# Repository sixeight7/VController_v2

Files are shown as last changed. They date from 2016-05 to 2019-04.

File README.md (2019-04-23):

# VController version 2
Second version of the dedicated MIDI controller for Boss GP-10  / Roland GR-55 / Roland VG-99 and Zoom G3
The latest version is the VController version 3: https://github.com/sixeight7/VController_v3. The firmware of version 3 can be compiled for this hardware! That way you get all the features of version 3 for this device as well!

# Features
* Patch selection - view of patch names for all devices.
* Read and show correct effect state for all devices. Different colours for different types of effects (eg. modulation is blue, amps are red, delays are green, etc)
* GP10 and GR55: change fixed parameters and cc assigns on each patch. Display tells you which parameter is changed and buttons have a colour that shows you the type of FX you select.
* VG99: pedal simulates an FC300 for CTL-1 to CTL-8. Parameter names and colours displayed for the most common parameters. CC assigns and fixed parameters also possible.
* For fixed parameters three/four and five state switches can be programmed
* Zoom G3: support of patch names / control of the 6 effects (on/off) - FX name is displayed, tap tempo.
* Global Tap Tempo: all devices pick up the tempo from the V-Controller. There is the option to keep this tempo on all patches on all devices.
* US-20 simulation: smart muting of GP10, GR55 or VG99 by switching off the COSM guitar/synth/normal PU on the devices that are not active.
* Autobass mode: sends a CC message with the number of the lowest string that is being played (CC #15)

# Hardware
Teensy 3.2, 16 switches and 16 neopixel LEDs, 13 1602 LCD display, some additional parts and an enclosure.
See my project blog for details and schematic.

# Software
Developed on Teensy 3.2 
Make sure you have the https://bitbucket.org/fmalpartida/new-liquidcrystal/downloads/LiquidCrystal_V1.2.1.zip library installed. It is the only non-standard library used in this sketch.

Start with VController_v2.ino in the VController_v2 folder to browse this code. It has the main setup and loop from where all the other files are called.

I tried to seperate the different tasks of the VController in the different files. Complete seperation is not possible, but it helps a great deal in finding stuff back.

Short desciption of each file in the VController_v2 folder:

* VController_v2.ino: The main file, that will call all the other ones in the right order.
* Commands.ino: shows the commands that can be used in the configuration of the VController
* Config.ino: configuration of what each switch does (on a page)
* Devices.ino: contains the basic settings and variables for the devices.
* EEPROM.ino: deals with putting some settings in memory.
* LCD.ino: sets up hardware for the LCD and decides what to put on the screen.
* LEDs.ino: sets up the neopixel LEDs and decides when to light up which one.
* MIDI.ino: sets up the MIdI hardware and provides the basic functions
* MIDI_FC300.ino: deals with specific midi functions for the FC 300.
* MIDI_GP10.ino: deals with specific midi functions for the Boss GP-10.
* MIDI_GR55.ino: deals with specific midi functions for the Roland GR-55.
* MIDI_VG99.ino: deals with specific midi functions for the Roland VG-99.
* MIDI_ZG3.ino: deals with specific midi functions for the Zoom G3
* Page.ino: here a page of switches is read from the configuration and the correct MIDI function is called from here.
* Switch_check.ino: checks whether a switch is pressed, released or pressed for a longer time.
* Switch_control.ino: basically deals with patch changes and provides the framework for the stompbox modes.
* z_log.ino: Log of latest changes.

More details are up in my project blog.

# To do
* Adding Direct select
* Adding parameter range option - to allow programming devices from the VController
* Add song and set mode.

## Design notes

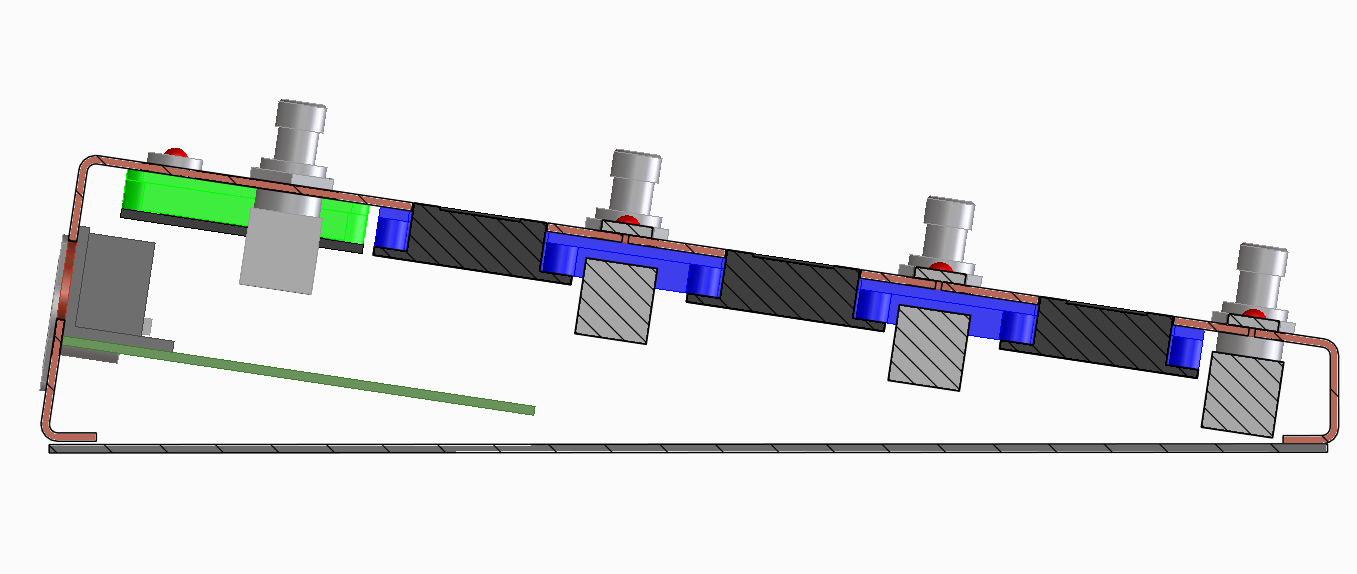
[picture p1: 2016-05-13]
Enclosure/Metal/side_view.png

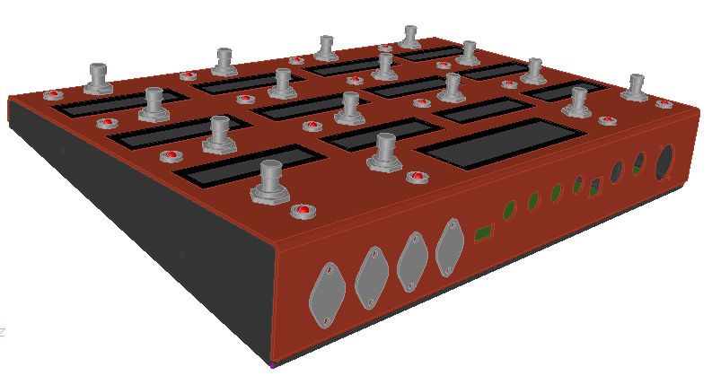
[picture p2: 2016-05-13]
Enclosure/VC2 final back.png

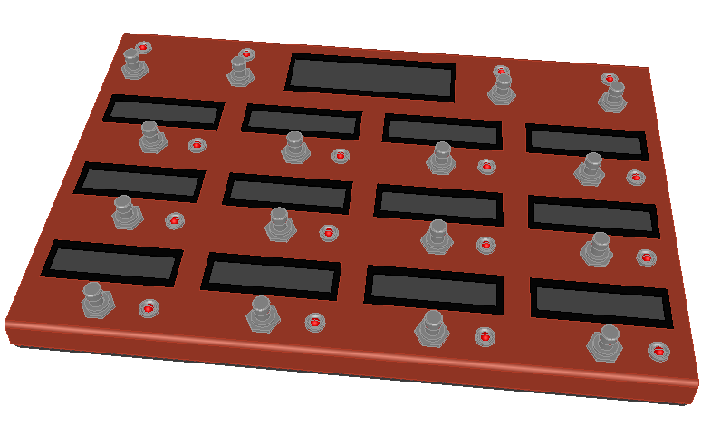
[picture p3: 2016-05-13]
Enclosure/VC2 final front.png

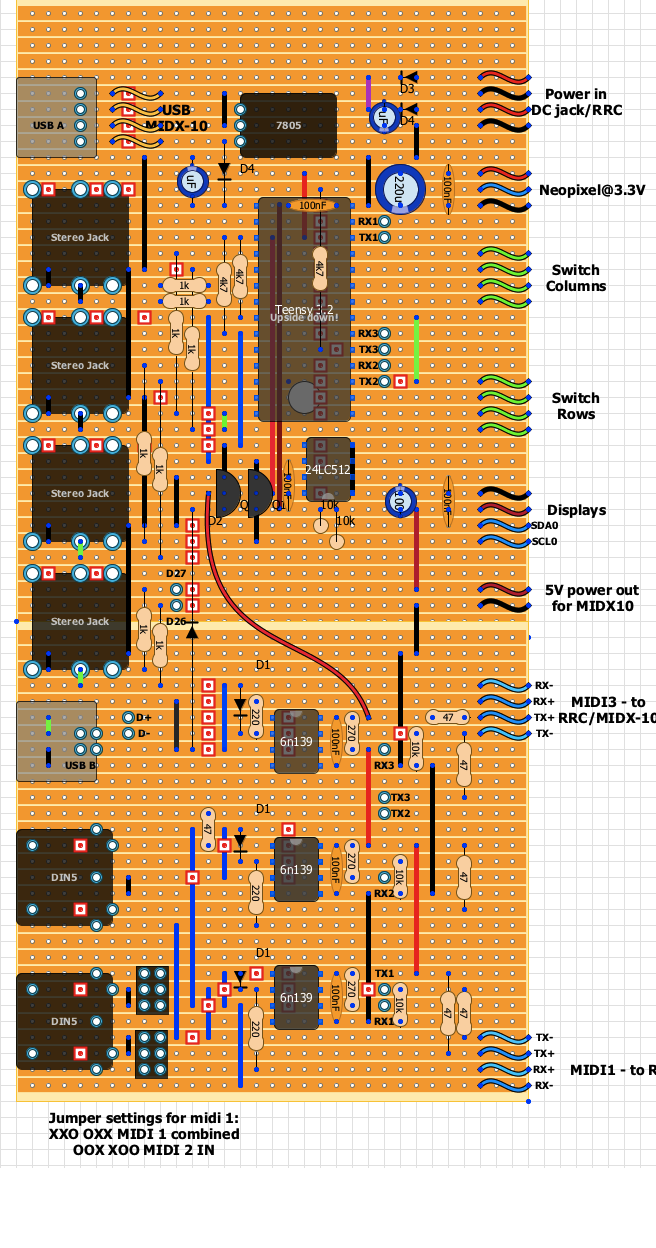
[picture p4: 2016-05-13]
PCB/VController PCB v2.4.png

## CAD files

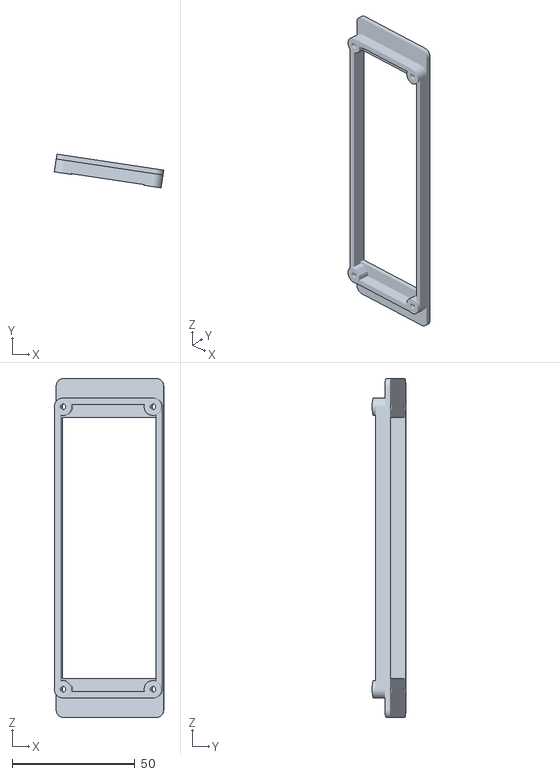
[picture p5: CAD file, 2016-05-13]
Enclosure/3D printing/Large LCD support diameter_2_5.stl
44.6 x 13.7 x 138.0

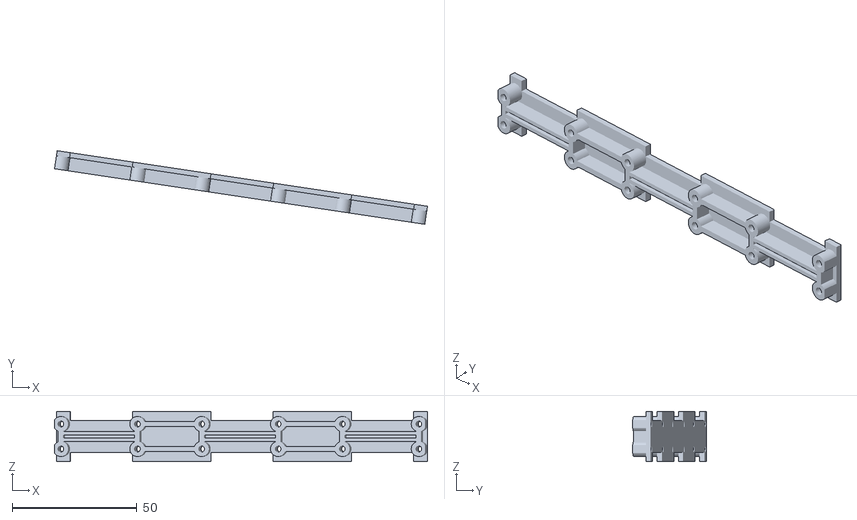
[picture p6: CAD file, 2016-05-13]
Enclosure/3D printing/Small 3xLCD support diameter_2_5.stl
149.4 x 29.5 x 20.2

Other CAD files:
Enclosure/Metal/bottom_sheet.dxf
Enclosure/Metal/top_sheet.dxf
Enclosure/Metal/bottom_sheet.dwg
Enclosure/Metal/top_sheet.dwg

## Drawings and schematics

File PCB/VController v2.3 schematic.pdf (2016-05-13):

220 47 | 47 | 1k8 270 220 4747 | 1k8 270 220 4747 | 1k8 270

A

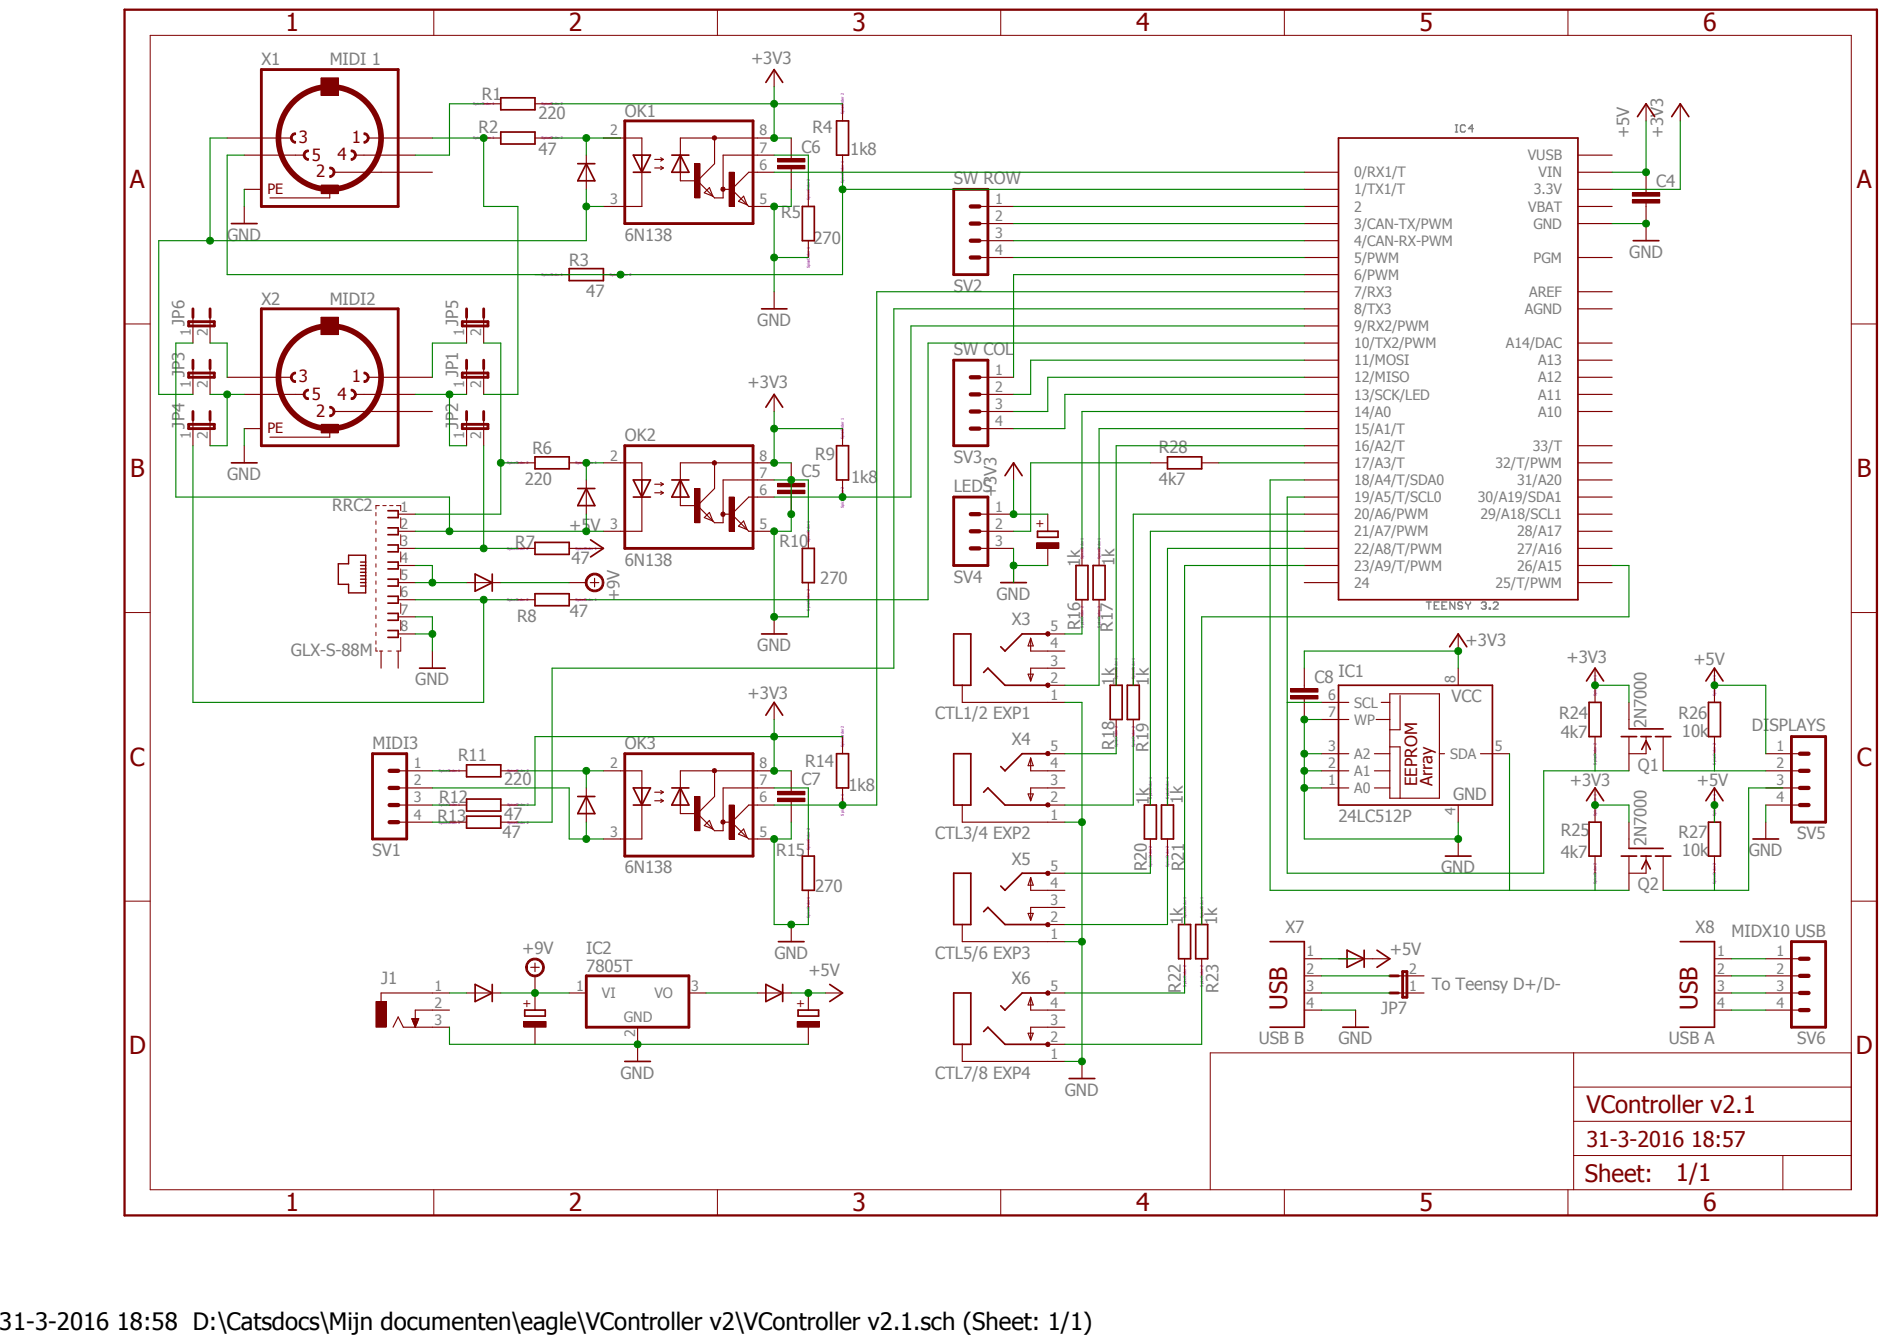
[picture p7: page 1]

5 | | SW ROW

SpiceOrder 1 SpiceOrder 2

31-3-2016 18:58 D:\Catsdocs\Mijn documenten\eagle\VController v2\VController v2.1.sch (Sheet: 1/1)

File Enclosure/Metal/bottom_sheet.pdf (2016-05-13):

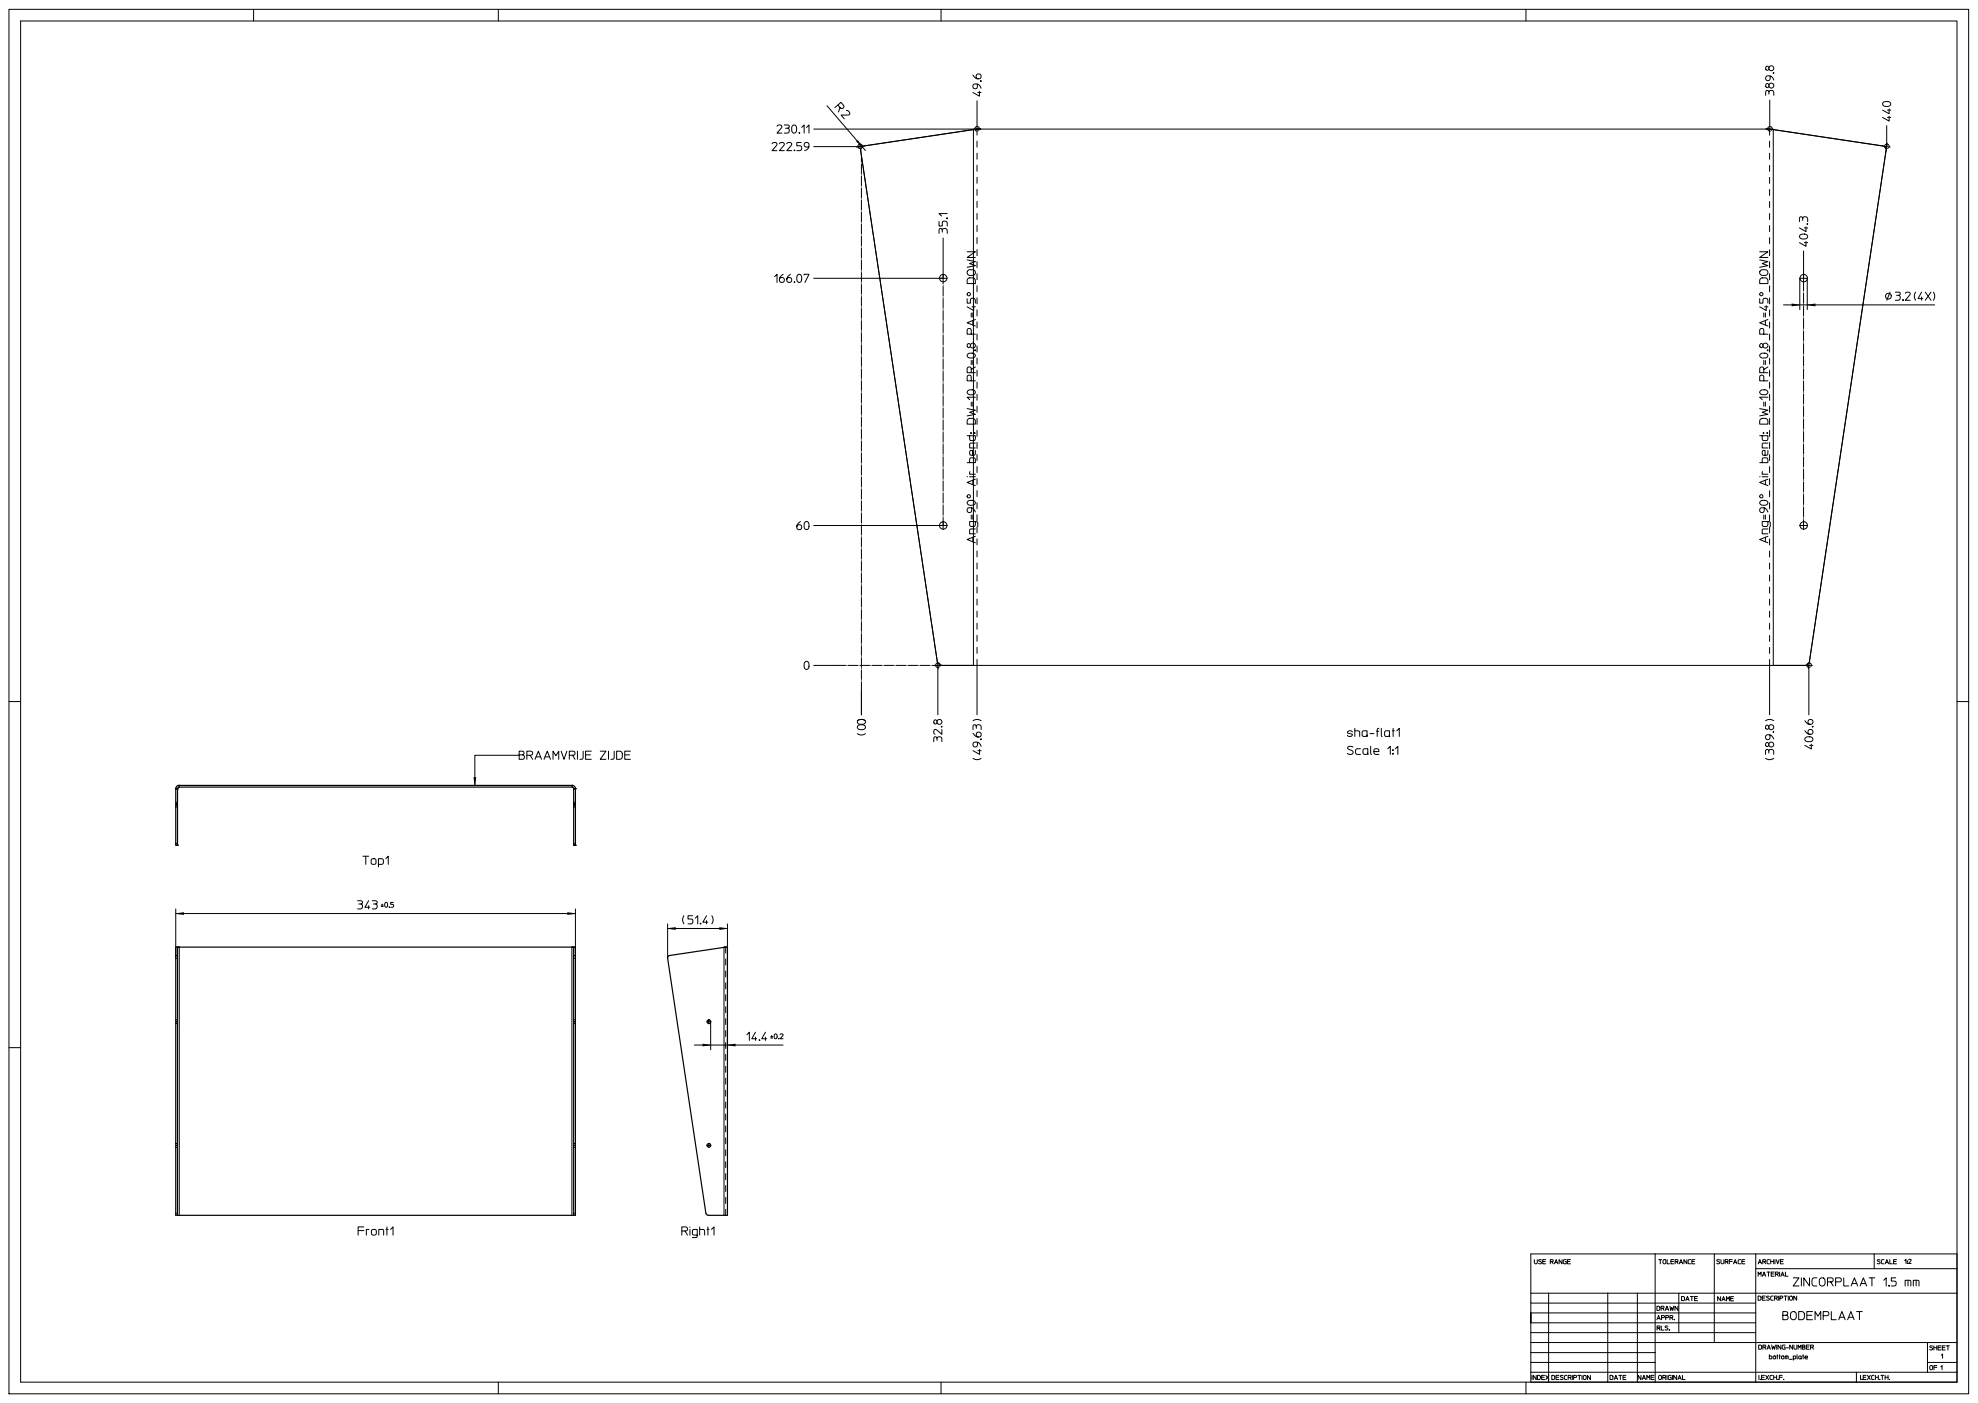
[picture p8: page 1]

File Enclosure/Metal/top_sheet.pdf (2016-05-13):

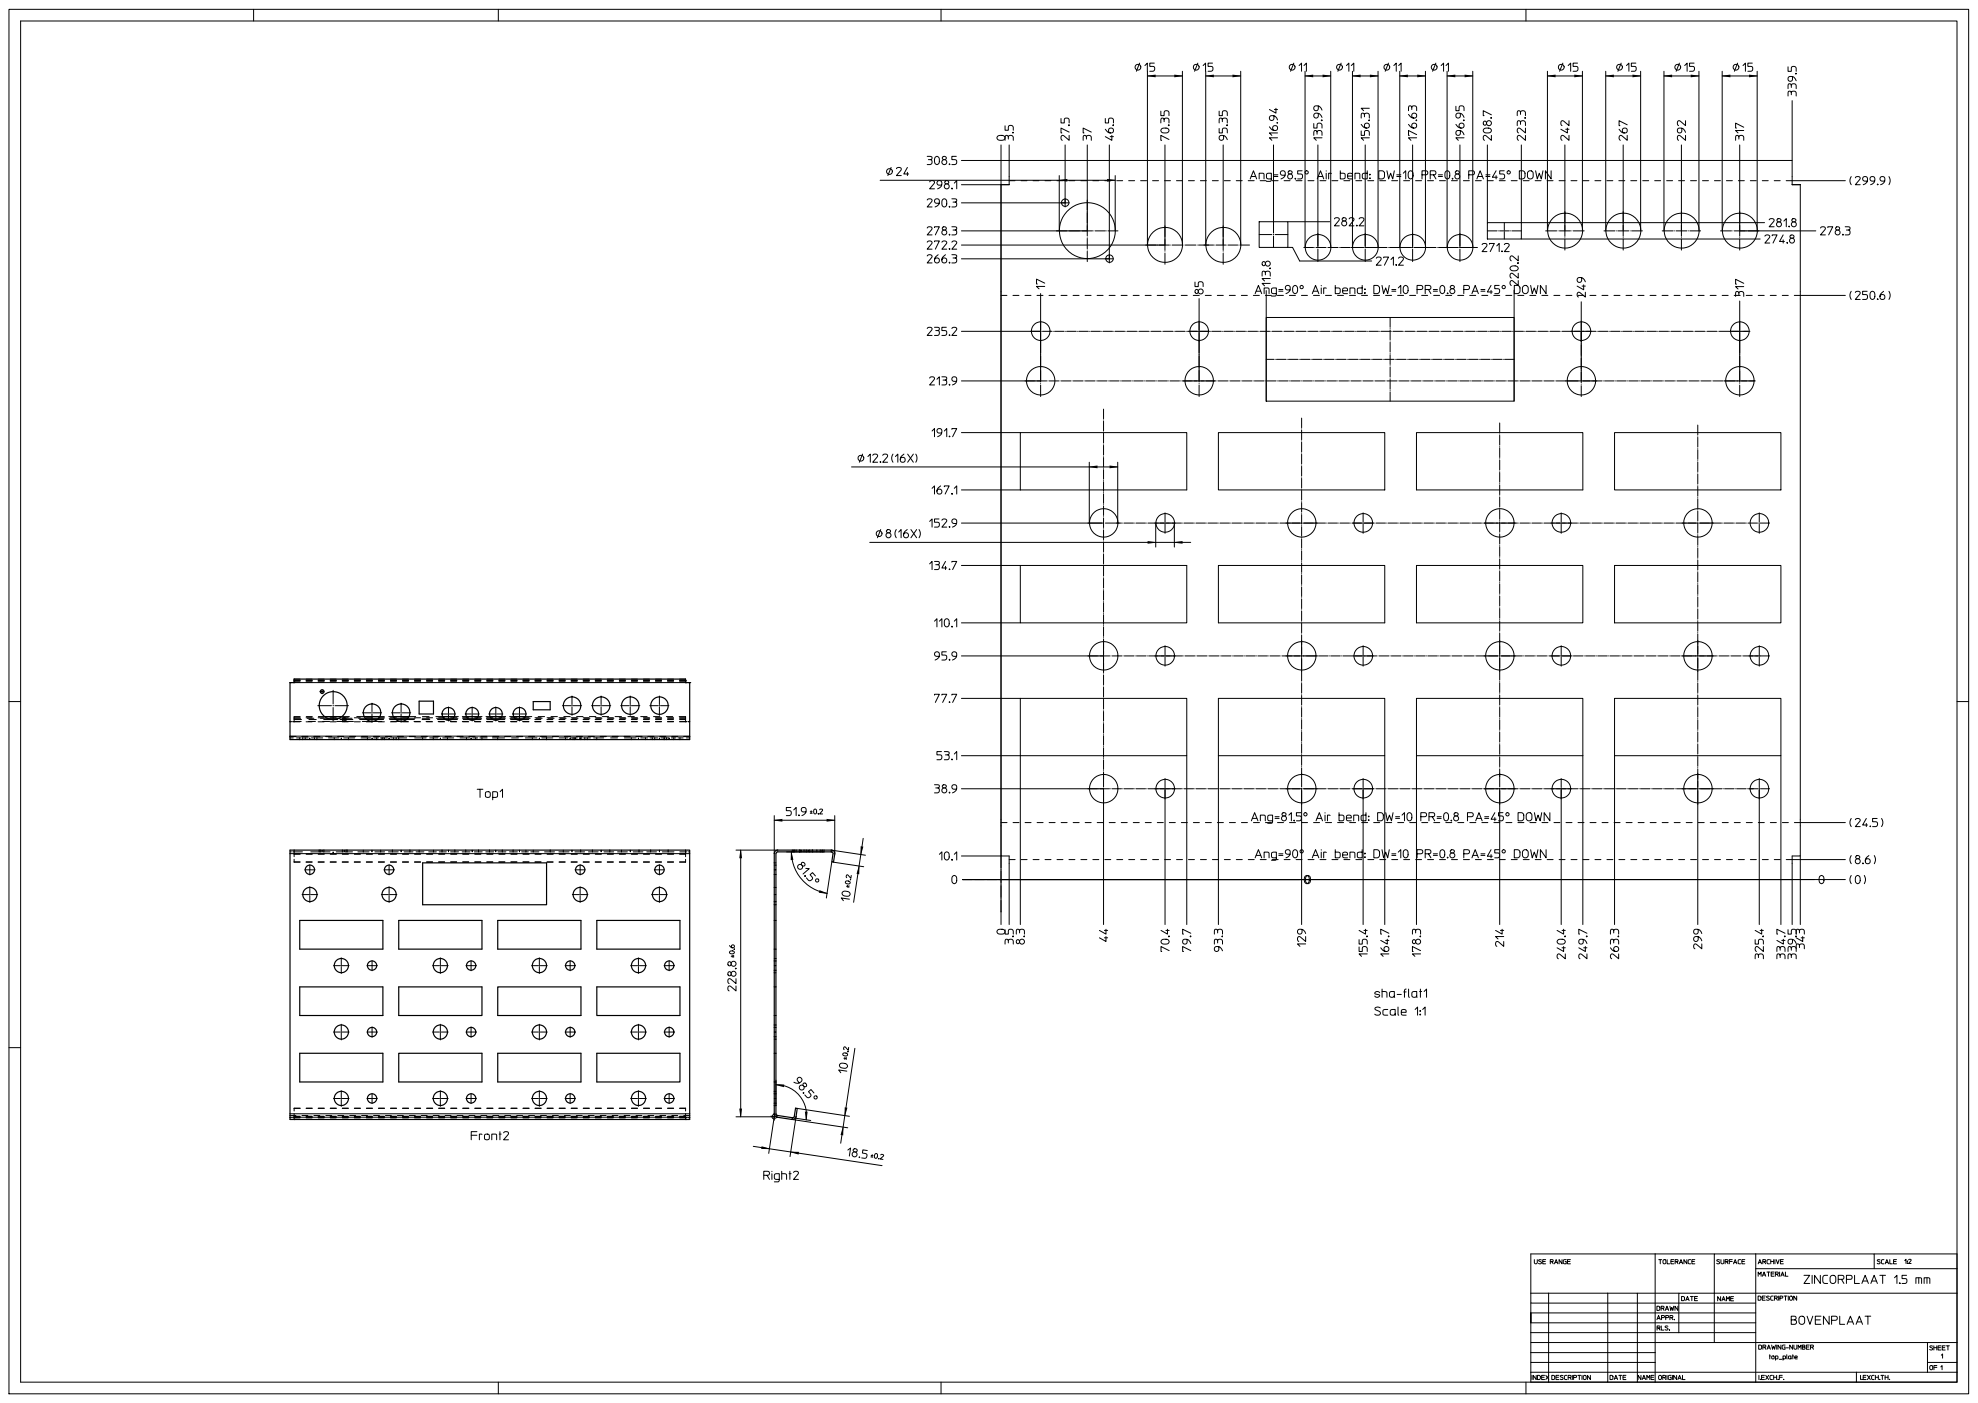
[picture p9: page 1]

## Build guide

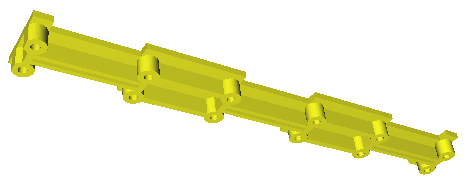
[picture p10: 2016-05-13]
Enclosure/3D printing/Small 3xLCD support diameter_2_5.png

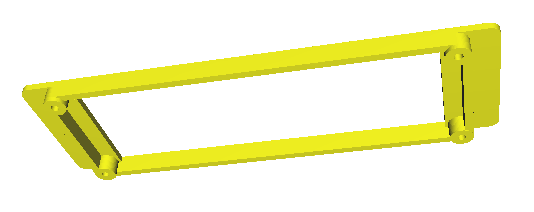
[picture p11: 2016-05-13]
Enclosure/3D printing/Large LCD support diameter_2_5.png

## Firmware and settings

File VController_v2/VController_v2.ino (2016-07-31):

/****************************************************************************
**
** Copyright (C) 2015 Catrinus Feddema
** All rights reserved.
** This file is part of "VController v2" teensy software.
**
** This program is free software; you can redistribute it and/or modify
** it under the terms of the GNU General Public License as published by
** the Free Software Foundation; either version 2 of the License, or
** (at your option) any later version.
**
** This program is distributed in the hope that it will be useful,
** but WITHOUT ANY WARRANTY; without even the implied warranty of
** MERCHANTABILITY or FITNESS FOR A PARTICULAR PURPOSE.  See the
** GNU General Public License for more details.
**
** You should have received a copy of the GNU General Public License along
** with this program; if not, write to the Free Software Foundation, Inc.,
** 51 Franklin Street, Fifth Floor, Boston, MA 02110-1301 USA.
**
****************************************************************************/

// Documentation on the bottom of this page

void setup() {
  setup_LED_control(); //Should be first, to reduce startup flash of LEDs
  setup_eeprom();
  setup_LCD_control();
  setup_debug();
  setup_switch_check();
  setup_switch_control();
  setup_page();
  setup_MIDI_common();
}

void loop() {
  main_switch_check(); // Check for switches pressed
  main_switch_control(); //If switch is pressed, take the configured action
  main_LED_control(); //Check update of LEDs
  main_LCD_control(); //Check update of displays
  main_MIDI_common(); //Read MIDI ports
  main_page(); // Check update of entire page
}

bool debug_active = true; // Switch debugging on or off here

void setup_debug() {
  if (debug_active) {
    Serial.begin(115200);
    delay(3000); // Wait until the serial communication is ready
    Serial.println("VController v2 started...");
  }
}

#define DEBUGMSG if (debug_active) Serial.println //Use this command for debug purposes

/****** Documentation VController V2 *********
VController version 2.

Hardware;
- 16 momentary switches connected in keypad matrix
- 16 neopixel LEDs
- 12 LCD displays for first 12 switches + main LCD display - all 16x2 character displays
- Teensy 3.1 (or Teensy LC with limited number of devices)
- 3 MIDI input/outputs and MIDI over USB
- Extra EEPROM Flash memory: 24LC512

Software features:
- Patch and parameter control for Boss GP-10, Roland GR-55, Roland VG-99 and Zoom G3
- Patchnames are read from devices
- Parameter states and assigns are read from devices
- Programmable pages of switches. There can be programmed on the Config page

Software structure:
- Initialization of LCDs, LEDs and MIDI ports
- Configuration of the switches is done in the page[] array on the Config page.
- On startup, detection of devices, page change or patch change the current page is loaded in the SP[] array (void load_page)
- After the page is loaded, the patchnames and parameter states are read (void Request_first_switch, Request_next_switch and Request_current_switch)
- Main loop checks for switches being pressed (Switch_check/Switch Control), midi received and update of LCD and LED states.

*/

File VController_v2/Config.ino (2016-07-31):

// Please read VController_v2.ino for information about the license and authors

// Configuration of the VController

#define NUMBER_OF_PAGES 11
#define NUMBER_OF_SWITCHES 16
#define NUMBER_OF_EXTERNAL_SWITCHES 8
#define NUMBER_OF_COMMANDS 3 // The number of commands one button can execute

struct Cmd_struct {
  uint8_t Type;
  uint8_t Data1;
  uint8_t Data2;
  uint8_t Value1;
  uint8_t Value2;
  uint8_t Value3;
  uint8_t Value4;
  uint8_t Value5;
};

struct Switch_struct {
  //char Label[17]; // Overrule label for switch
  Cmd_struct Cmd[NUMBER_OF_COMMANDS];
};

struct Page_struct {
  char Title[17];
  Switch_struct Switch[NUMBER_OF_SWITCHES];
};

uint8_t Current_page = 0;
uint8_t Previous_page = 0;

// Configuration of the pedal in PROGMEM
// All RELSEL and ASSIGN commands only work in first position!
#define PAGE_UNIT_OFF 0
#define PAGE_MODE_SELECT 1
#define PAGE_GP10_RELSEL 2
#define PAGE_GP10_PARAMETER 3
#define PAGE_GR55_RELSEL 4
#define PAGE_GR55_PARAMETER 5
#define PAGE_VG99_RELSEL 6
#define PAGE_VG99_PARAMETER 7
#define PAGE_COMBO1 8
#define PAGE_COMBO2 9
#define PAGE_ZG3_RELSEL 10

const PROGMEM Page_struct Page[NUMBER_OF_PAGES] = {
  // ******************************* PAGE 00 *************************************************
  { // Page settings:
    "                ", // Page title: Unit is off
    { // Switch settings:
      {{ {NOTHING}, {NOTHING}, {NOTHING} }}, // ** Switch 01 **
      {{ {NOTHING}, {NOTHING}, {NOTHING} }}, // ** Switch 02 **
      {{ {NOTHING}, {NOTHING}, {NOTHING} }}, // ** Switch 03 **
      {{ {NOTHING}, {NOTHING}, {NOTHING} }}, // ** Switch 04 **
      {{ {NOTHING}, {NOTHING}, {NOTHING} }}, // ** Switch 05 **
      {{ {NOTHING}, {NOTHING}, {NOTHING} }}, // ** Switch 06 **
      {{ {NOTHING}, {NOTHING}, {NOTHING} }}, // ** Switch 07 **
      {{ {NOTHING}, {NOTHING}, {NOTHING} }}, // ** Switch 08 **
      {{ {NOTHING}, {NOTHING}, {NOTHING} }}, // ** Switch 09 **
      {{ {NOTHING}, {NOTHING}, {NOTHING} }}, // ** Switch 10 **
      {{ {NOTHING}, {NOTHING}, {NOTHING} }}, // ** Switch 11 **
      {{ {NOTHING}, {NOTHING}, {NOTHING} }}, // ** Switch 12 **
      {{ {NOTHING}, {NOTHING}, {NOTHING} }}, // ** Switch 13 **
      {{ {NOTHING}, {NOTHING}, {NOTHING} }}, // ** Switch 14 **
      {{ {NOTHING}, {NOTHING}, {NOTHING} }}, // ** Switch 15 **
      {{ {STANDBYE}, {NOTHING}, {NOTHING} }}, // ** Switch 16 **
    }
  },
  // ******************************* PAGE 01 *************************************************
  { // Page settings:
    "MODE SELECT    ", // Page title: Unit is off
    { // Switch settings:
      {{ {NOTHING}, {NOTHING}, {NOTHING} }}, // ** Switch 01 **
      {{ {NOTHING}, {NOTHING}, {NOTHING} }}, // ** Switch 02 **
      {{ {NOTHING}, {NOTHING}, {NOTHING} }}, // ** Switch 03 **
      {{ {SELECT_PAGE, PAGE_COMBO2}, {NOTHING}, {NOTHING} }}, // ** Switch 04 **
      {{ {SELECT_PAGE, PAGE_GP10_PARAMETER}, {NOTHING}, {NOTHING} }}, // ** Switch 05 **
      {{ {SELECT_PAGE, PAGE_GR55_PARAMETER}, {NOTHING}, {NOTHING} }}, // ** Switch 06 **
      {{ {SELECT_PAGE, PAGE_VG99_PARAMETER}, {NOTHING}, {NOTHING} }}, // ** Switch 07 **
      {{ {SELECT_PAGE, PAGE_COMBO1}, {NOTHING}, {NOTHING} }}, // ** Switch 08 **
      {{ {SELECT_PAGE, PAGE_GP10_RELSEL}, {NOTHING}, {NOTHING} }}, // ** Switch 09 **
      {{ {SELECT_PAGE, PAGE_GR55_RELSEL}, {NOTHING}, {NOTHING} }}, // ** Switch 10 **
      {{ {SELECT_PAGE, PAGE_VG99_RELSEL}, {NOTHING}, {NOTHING} }}, // ** Switch 11 **
      {{ {SELECT_PAGE, PAGE_ZG3_RELSEL}, {NOTHING}, {NOTHING} }}, // ** Switch 12 **
      {{ {NOTHING}, {NOTHING}, {NOTHING} }}, // ** Switch 13 **
      {{ {NOTHING}, {NOTHING}, {NOTHING} }}, // ** Switch 14 **
      {{ {SELECT_NEXT_DEVICE}, {NOTHING}, {NOTHING} }}, // ** Switch 15 **
      {{ {STANDBYE}, {NOTHING}, {NOTHING} }}, // ** Switch 16 **
    }
  },
  // ******************************* PAGE 02 *************************************************
  { // Page settings:
    "GP-10", // Page title
    { // Switch settings:
      {{ {GP10_RELSEL, 1, 10}, {GR55_MUTE}, {VG99_MUTE} }}, // ** Switch 01 **
      {{ {GP10_RELSEL, 2, 10}, {GR55_MUTE}, {VG99_MUTE} }}, // ** Switch 02 **
      {{ {GP10_RELSEL, 3, 10}, {GR55_MUTE}, {VG99_MUTE} }}, // ** Switch 03 **
      {{ {GP10_RELSEL, 4, 10}, {GR55_MUTE}, {VG99_MUTE} }}, // ** Switch 04 **
      {{ {GP10_RELSEL, 5, 10}, {GR55_MUTE}, {VG99_MUTE} }}, // ** Switch 05 **
      {{ {GP10_RELSEL, 6, 10}, {GR55_MUTE}, {VG99_MUTE} }}, // ** Switch 06 **
      {{ {GP10_RELSEL, 7, 10}, {GR55_MUTE}, {VG99_MUTE} }}, // ** Switch 07 **
      {{ {GP10_RELSEL, 8, 10}, {GR55_MUTE}, {VG99_MUTE} }}, // ** Switch 08 **
      {{ {GP10_RELSEL, 9, 10}, {GR55_MUTE}, {VG99_MUTE} }}, // ** Switch 09 **
      {{ {GP10_RELSEL, 10, 10}, {GR55_MUTE}, {VG99_MUTE} }}, // ** Switch 10 **
      {{ {GP10_PARAMETER, 16, TOGGLE, 1, 0}, {NOTHING}, {NOTHING} }}, // ** Switch 11 **
      {{ {TAP_TEMPO}, {NOTHING}, {NOTHING} }}, // ** Switch 12 **
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

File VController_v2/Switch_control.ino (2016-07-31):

// Please read VController_v2.ino for information about the license and authors

// Here an action is taken after a switch is pressed. This action is read from the config file

void setup_switch_control()
{
  //SCO_reset_all_switch_states();
  //PAGE_load_current(true);
}

// Do something with buttons being pressed
void main_switch_control()  // Checks if a button has been pressed and check out which functions have to be executed
{
  if (switch_pressed > 0) {
    if (switch_pressed > 16) LCD_show_status_message("Switch " + String(switch_pressed));
    else SCO_switch_pressed_commands(Current_page, switch_pressed - 1);
  }

  if (switch_released > 0) {
    SCO_switch_released_commands(Current_page, switch_released - 1);
  }

  if (switch_long_pressed > 0) {
    if (switch_long_pressed == 16) SCO_switch_VController_standbye(); //Switch VController on/off on long press button 16
    SCO_switch_long_pressed_commands(Current_page, switch_long_pressed - 1);
  }

  if (expr_ped_changed > 0) {
    //if (expr_ped_changed == 1) SCO_switch_pressed_commands(Current_page, 16);
    uint8_t index = (expr_ped_changed - 1);
    MIDI_send_CC(Exp_CC_number[index], Expr_value, Exp_CC_channel[index], Exp_CC_port[index]); // Just send a CC message - can be set on the Config page
    LCD_show_status_message("CC#" + String(Exp_CC_number[index]) + ": " + String(Expr_value));
  }

  SCO_update_tap_tempo_LED();
}

void SCO_switch_pressed_commands(uint8_t Pg, uint8_t Sw) {
  SP[Sw].Pressed = true;

  // Run through the commands:
  for (uint8_t c = 0; c < NUMBER_OF_COMMANDS; c++) {
    //execute command
    uint8_t Type, Data1, Data2;
    //if (Sw < NUMBER_OF_SWITCHES) { // It is a regular switch
    Type = Page[Pg].Switch[Sw].Cmd[c].Type;
    Data1 = Page[Pg].Switch[Sw].Cmd[c].Data1;
    Data2 = Page[Pg].Switch[Sw].Cmd[c].Data2;
    //}
    /*else { // It is an external switch
      Type = Ext_switch[Sw].Cmd[c].Type;
      Data1 = Ext_switch[Sw].Cmd[c].Data1;
      Data2 = Ext_switch[Sw].Cmd[c].Data2;
      LCD_show_status_message("Type: " + String(Type));
    }*/

    switch (Type) {
      case TAP_TEMPO:
        SCO_global_tap_tempo_press();
        break;
      case GP10_PATCH:
        GP10_patch_select(Data1 - 1);
        GP10_patch_name = SP[Sw].Label; // Store current patch name
        break;
      case GP10_RELSEL:
        GP10_patch_select(SP[Sw].PP_number);
        GP10_patch_name = SP[Sw].Label; // Store current patch name
        break;
      case GP10_BANK_UP:
        GP10_bank_updown(UP, Data1);
        break;
      case GP10_BANK_DOWN:
        GP10_bank_updown(DOWN, Data1);
        break;
      case GP10_PARAMETER:
        if (c == 0) SCO_update_parameter_state(Sw);
        GP10_parameter_press(Sw, c, Data1);
        break;
      case GP10_ASSIGN:
        if (c == 0) SCO_update_parameter_state(Sw);
        GP10_assign_press(Sw);
        break;
      case GP10_MUTE:
        GP10_mute();
        break;
      case GR55_PATCH:
        if ((Data1 >= 1) && (Data2 >= 1) && (Data2 <= 3)) GR55_patch_select(((Data1 - 1) * 3) + (Data2 - 1));
        GR55_patch_name = SP[Sw].Label; // Store current patch name
        break;
      case GR55_RELSEL:
        GR55_patch_select(SP[Sw].PP_number);
        GR55_patch_name = SP[Sw].Label; // Store current patch name
        break;
      case GR55_BANK_UP:
        GR55_bank_updown(UP, Data1);
        break;
      case GR55_BANK_DOWN:
        GR55_bank_updown(DOWN, Data1);
        break;
      case GR55_PARAMETER:
        if (c == 0) SCO_update_parameter_state(Sw);
        GR55_parameter_press(Sw, c, Data1);
        break;
      case GR55_ASSIGN:
        if (c == 0) SCO_update_parameter_state(Sw);
        GR55_assign_press(Sw);
        break;
      case GR55_MUTE:
        GR55_mute();
        break;
      case VG99_PATCH:
        VG99_patch_select((Data2 * 100) + Data1 - 1);
        VG99_patch_name = SP[Sw].Label; // Store current patch name
        break;
      case VG99_RELSEL:
        VG99_patch_select(SP[Sw].PP_number);
        VG99_patch_name = SP[Sw].Label; // Store current patch name
        break;
      case VG99_BANK_UP:
        VG99_bank_updown(UP, Data1);
        break;
      case VG99_BANK_DOWN:
        VG99_bank_updown(DOWN, Data1);
        break;
      case VG99_PARAMETER:
        if (c == 0) SCO_update_parameter_state(Sw);
        VG99_parameter_press(Sw, c, Data1);
        break;
      case VG99_ASSIGN:
        if (c == 0) SCO_update_parameter_state(Sw);
        VG99_assign_press(Sw);
        break;
      case VG99_MUTE:
        VG99_mute();
        break;
      case ZG3_PATCH:
        ZG3_patch_select(Data1 - 1);
        ZG3_Remember_FXs(Sw);
        ZG3_patch_name = SP[Sw].Label; // Store current patch name
        break;
      case ZG3_RELSEL:
        ZG3_patch_select(SP[Sw].PP_number);
        ZG3_Remember_FXs(Sw);
        ZG3_patch_name = SP[Sw].Label; // Store current patch name
        break;
      case ZG3_BANK_UP:
        ZG3_bank_updown(UP, Data1);
        break;
      case ZG3_BANK_DOWN:
        ZG3_bank_updown(DOWN, Data1);
        break;
      case ZG3_FX_TOGGLE:
        if (c == 0) SCO_update_parameter_state(Sw);
        ZG3_FX_press(Sw, c, Data1);
        break;
      case SELECT_PAGE:
        SCO_select_page(Data1);
        break;
      case SELECT_NEXT_DEVICE:
        SCO_select_next_device();
        break;
      case COMBI_BANK_UP:
        SCO_combi_bank_updown(UP, Data1);
        break;
      case COMBI_BANK_DOWN:
        SCO_combi_bank_updown(DOWN, Data1);
        break;
      case STANDBYE:
        SCO_switch_VController_on();
        break;
      case MIDI_PC:
        MIDI_send_PC(Data1, Data2, Page[Pg].Switch[Sw].Cmd[c].Value1);
        break;
      case MIDI_NOTE:
        MIDI_send_note_on(Data1, Data2, Page[Pg].Switch[Sw].Cmd[c].Value1, Page[Pg].Switch[Sw].Cmd[c].Value2);
        break;
    }
  }
  update_LEDS = true;
  update_main_lcd = true;
}
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

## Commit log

2016-07-13 Added virtual LEDs
2016-07-31 Many fixes and additions
    [Commands.ino, Config.ino, Devices.ino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]
